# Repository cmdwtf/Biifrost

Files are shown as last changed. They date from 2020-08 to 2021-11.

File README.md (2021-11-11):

# Biifröst Bridge
A PCB bridge from Odiin to Screen

### Board Images
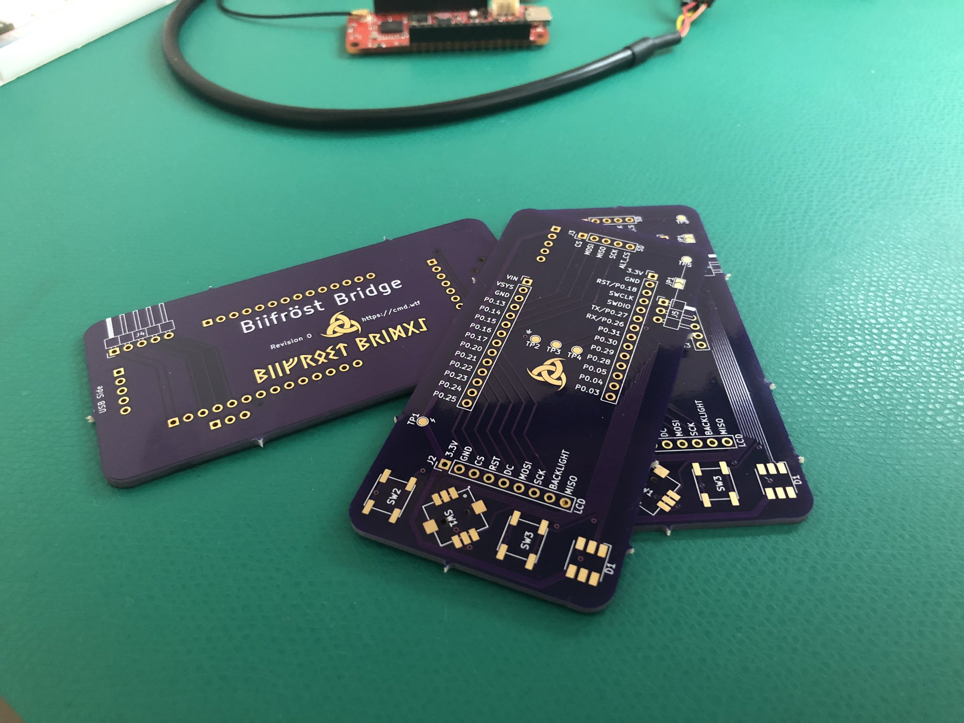
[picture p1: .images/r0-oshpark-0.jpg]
Revision 0 Fab 0
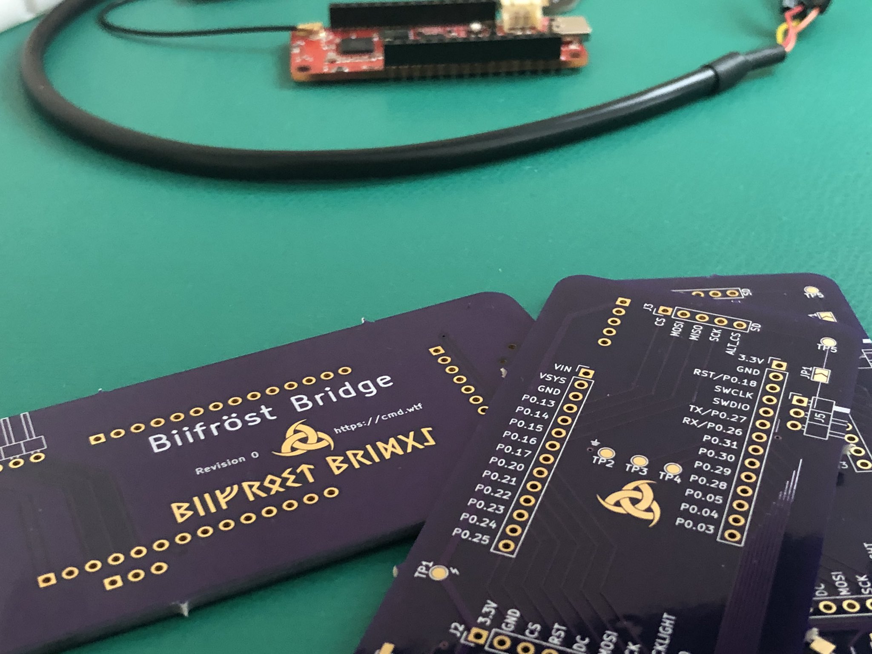
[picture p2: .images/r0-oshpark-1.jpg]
Revision 0 Fab 1
 
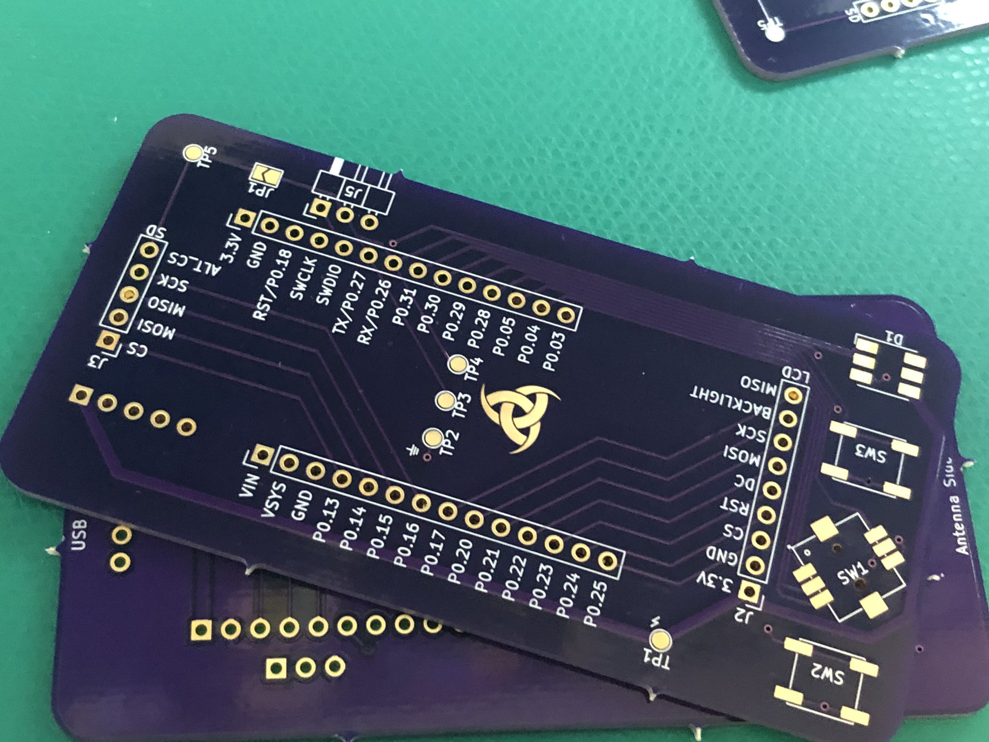
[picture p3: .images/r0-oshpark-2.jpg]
Revision 0 Fab 2
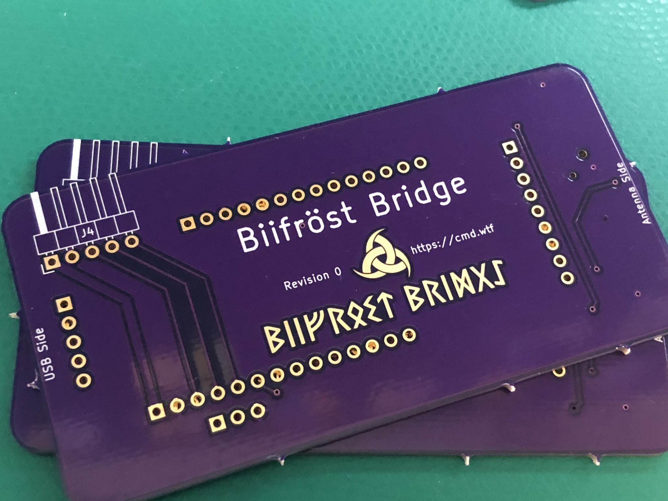
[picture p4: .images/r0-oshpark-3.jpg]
Revision 0 Fab 3
 
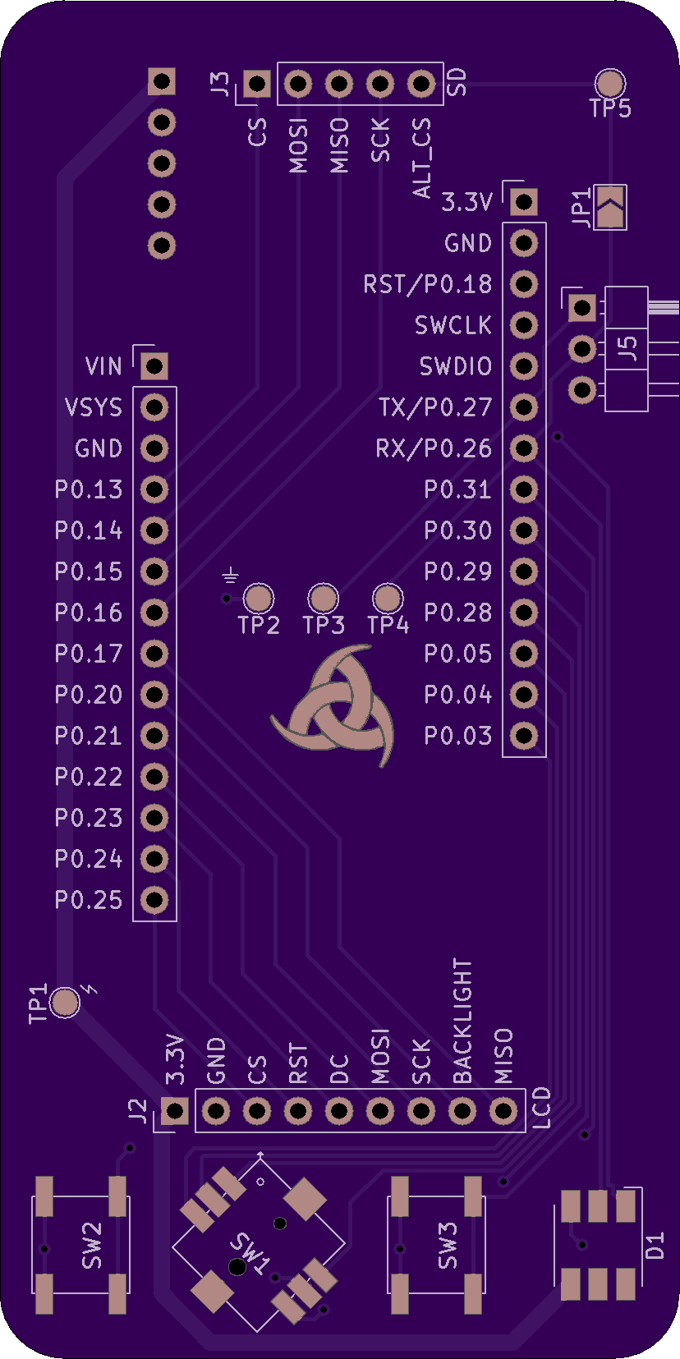
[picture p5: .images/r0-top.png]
Revision 0 Top
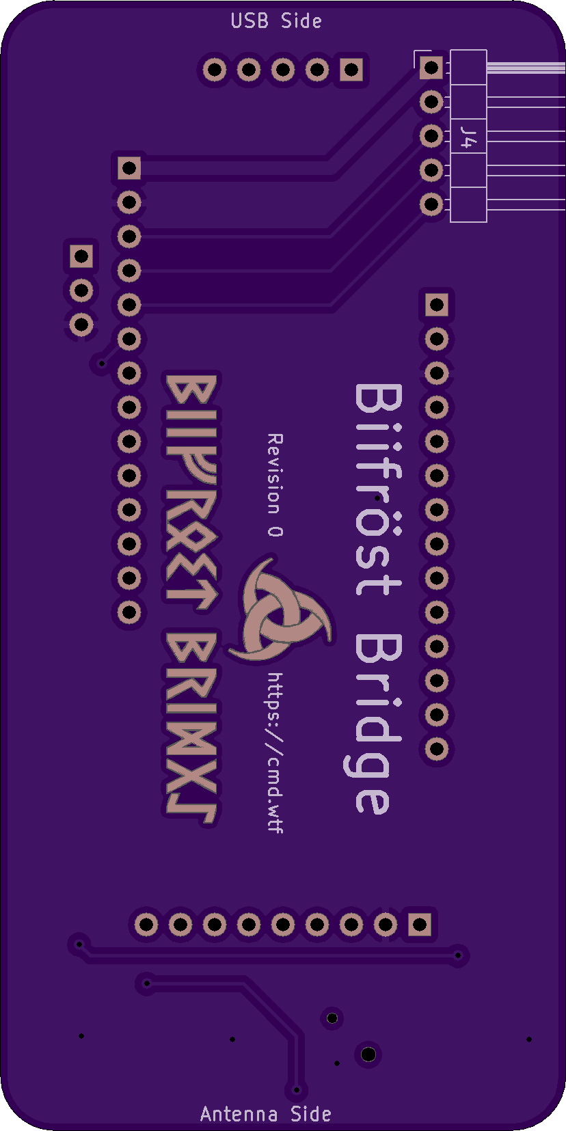
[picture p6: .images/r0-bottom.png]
Revision 0 Bottom
 

# EDA
Biifröst Bridge was designed and created with [KiCad EDA](https://kicad.org/) 5.1.6.

# License
This repository is licensed under Apache-2.0 WITH SHL-2.1. Please see LICENSE.md for more information.

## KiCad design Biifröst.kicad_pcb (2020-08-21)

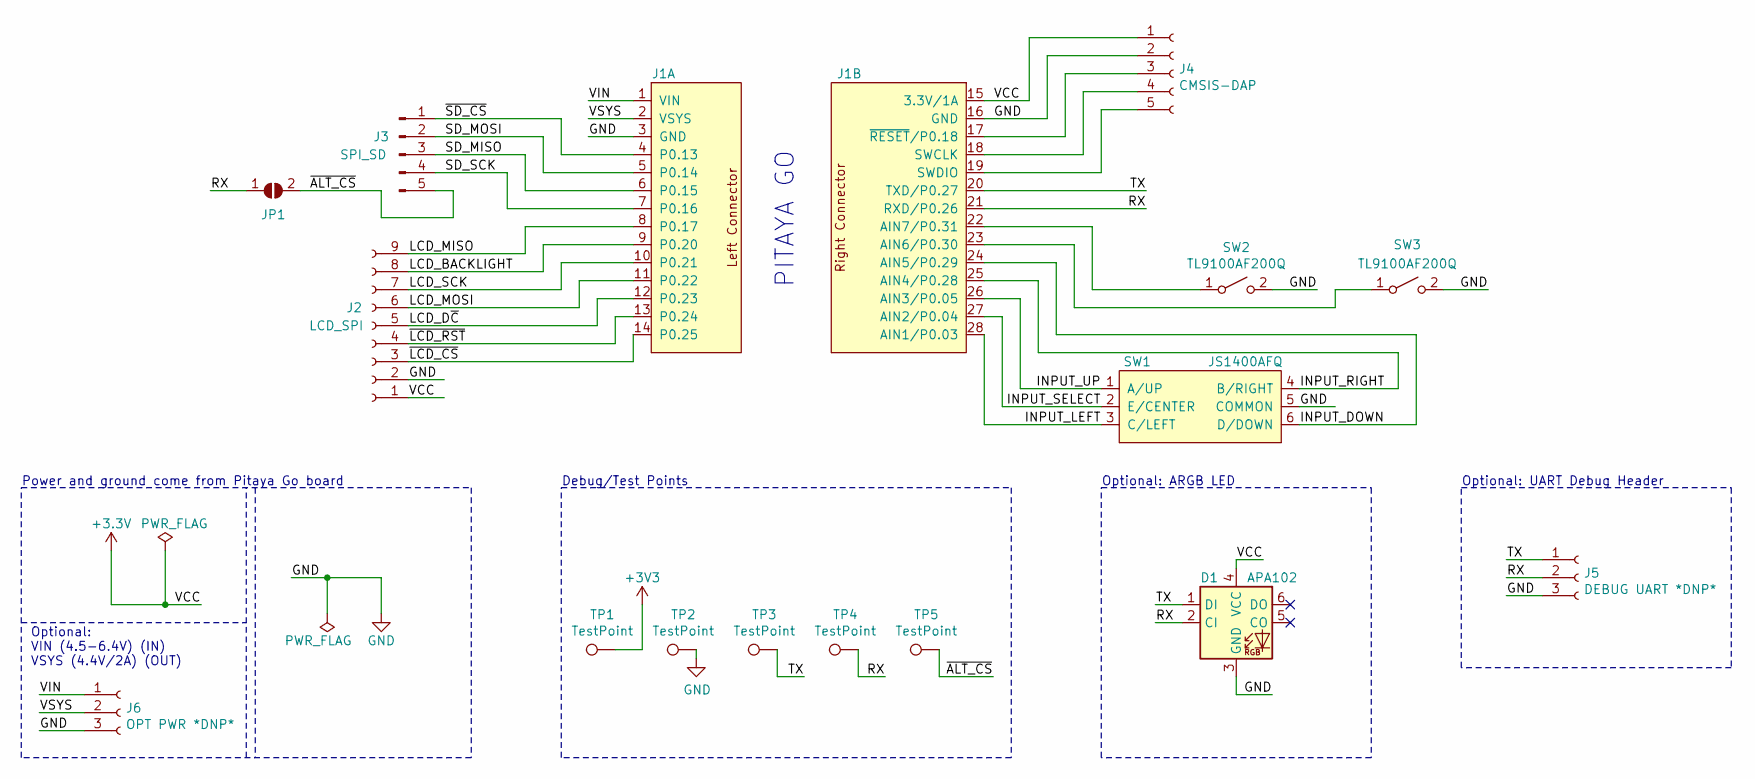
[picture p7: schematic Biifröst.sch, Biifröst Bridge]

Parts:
D1: APA102; LED_RGB_5050-6
J1: Pitaya_Go; Pitaya_Go_Headers
J2: LCD_SPI; PinHeader_1x09_P2.54mm_Vertical
J3: SPI_SD; PinHeader_1x05_P2.54mm_Vertical
J4: CMSIS-DAP; PinHeader_1x05_P2.54mm_Horizontal
J5: DEBUG UART *DNP*; PinHeader_1x03_P2.54mm_Horizontal
J6: OPT PWR *DNP*; PinHeader_1x03_P2.54mm_Horizontal
JP1: SolderJumper_2_Open; SolderJumper-2_P1.3mm_Open_TrianglePad1.0x1.5mm
SW1: JS1400AFQ; JS1400
SW2, SW3: TL9100AF200Q; TL9100
TP1, TP2, TP3, TP4, TP5: TestPoint; TestPoint_Pad_D1.5mm

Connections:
/INPUT_DOWN: J1.24 (AIN5/P0.29), SW1.6 (D/DOWN)
/INPUT_LEFT: J1.28 (AIN1/P0.03), SW1.3 (C/LEFT)
/INPUT_RIGHT: J1.25 (AIN4/P0.28), SW1.4 (B/RIGHT)
/INPUT_SELECT: J1.27 (AIN2/P0.04), SW1.2 (E/CENTER)
/INPUT_UP: J1.26 (AIN3/P0.05), SW1.1 (A/UP)
/LCD_BACKLIGHT: J1.9 (P0.20), J2.8
/LCD_D~C~: J1.12 (P0.23), J2.5
/LCD_MISO: J1.8 (P0.17), J2.9
/LCD_MOSI: J1.11 (P0.22), J2.6
/LCD_SCK: J1.10 (P0.21), J2.7
/RX: D1.2 (CI), J1.21 (RXD/P0.26), J5.2, JP1.1 (A), TP4.1
/SD_MISO: J1.6 (P0.15), J3.3
/SD_MOSI: J1.5 (P0.14), J3.2
/SD_SCK: J1.7 (P0.16), J3.4
/TX: D1.1 (DI), J1.20 (TXD/P0.27), J5.1, TP3.1
/VIN: J1.1 (VIN), J6.1
/VSYS: J1.2 (VSYS), J6.2
/~ALT_CS~: J3.5, JP1.2 (B), TP5.1
/~LCD_CS~: J1.14 (P0.25), J2.3
/~LCD_RST~: J1.13 (P0.24), J2.4
/~SD_CS~: J1.4 (P0.13), J3.1
GND: D1.3 (GND), J1.3 (GND), J1.16 (GND), J2.2, J4.2, J5.3, J6.3, SW1.5 (COMMON), SW2.2 (B), SW3.2 (B), TP2.1
unnamed: J1.17 (~RESET~/P0.18), J4.3
unnamed: J1.18 (SWCLK), J4.4
unnamed: J1.19 (SWDIO), J4.5
unnamed: J1.22 (AIN7/P0.31), SW2.1 (A)
unnamed: J1.23 (AIN6/P0.30), SW3.1 (A)

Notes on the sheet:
PITAYA GO
Power and ground come from Pitaya Go board
Optional: ARGB LED
Optional: UART Debug Header
Debug/Test Points
Optional: VIN (4.5-6.4V) (IN) VSYS (4.4V/2A) (OUT)

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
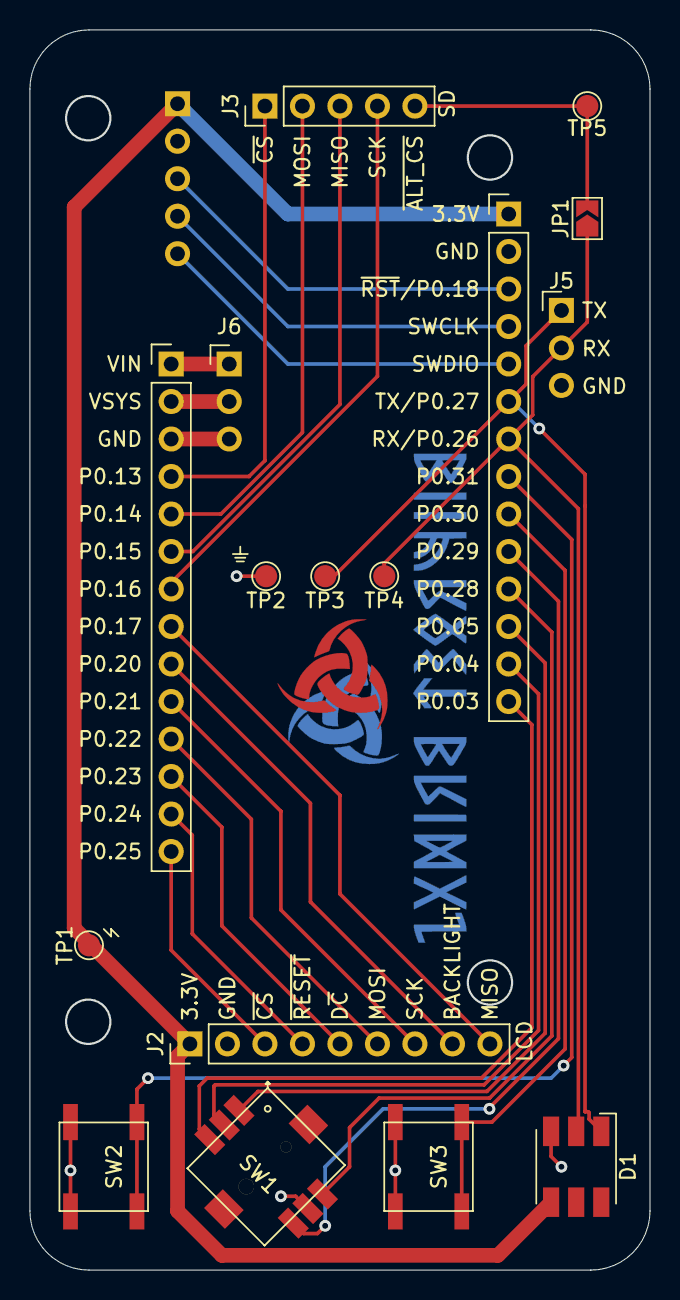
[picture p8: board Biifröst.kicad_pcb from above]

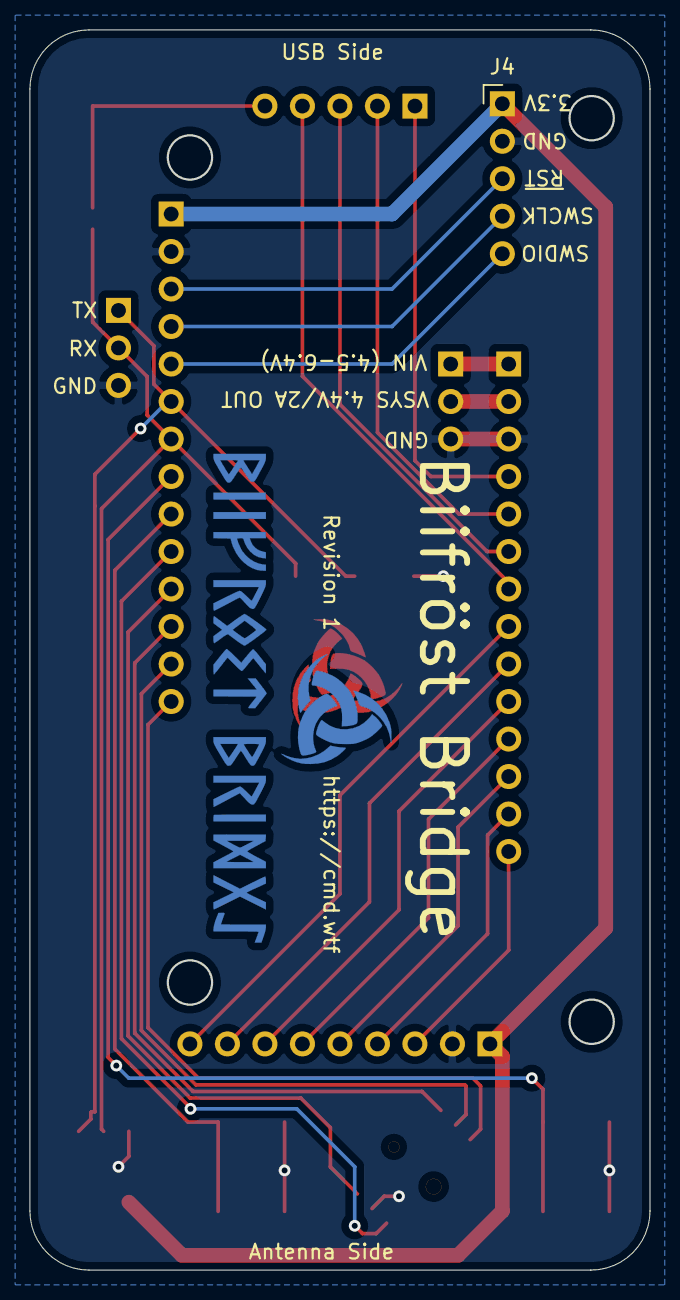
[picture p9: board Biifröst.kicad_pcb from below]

Board: 2 copper layers, 42.0 x 84.0 mm, 19 parts (3 on the bottom side), 28 nets.

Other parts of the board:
Ref**: Val**; Horn_of_Odin
Ref**#2: Val**; Logo
Ref**#3: Val**; Wordmark

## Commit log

2020-08-03 WIP r0.
    [Biifröst.kicad_pcb, Biifröst.sch]
2020-08-03 Add Wordmark/Icon for flair.
    [Biifröst.kicad_pcb]
2020-08-11 Add board images for r0.
2020-08-18 Add several models.
    Including Pitaya Go, both E-Switch types.
    Added some board dimensions too.
    [Biifröst.kicad_pcb]
2020-08-18 Update pins to have not bars where they should be.
    And fixed a dumb typo on a net name.
    [Biifröst.kicad_pcb, Biifröst.sch]
2020-08-19 Add actual board images, fab'd by oshpark.
2020-08-19 Add/adjust some silks. Bump to r1.
    Still need to test the apa102 at 3.3v before I send it up for another spin.
    [Biifröst.kicad_pcb, Biifröst.sch]
2020-08-21 Add VIN/VSYS breakout. Add 4 hole cuts that will line up with sister boards.
    2 hole cuts will align with the pitaya go holes (1 top, 1 bottom, on one side)
    2 hole cuts will align with the LCD board holes (1 top, 1 bottom, opposite side from pitaya.)
    Not perfectly ideal, but required no trace moves, and they may be useful.
    [Biifröst.kicad_pcb, Biifröst.sch]
2020-08-21 Add measurements to new hole cuts.
    [Biifröst.kicad_pcb]
2021-11-10 Update README.md
    https://forum.kicad.info/t/warning-avoid-all-links-to-kicad-pcb-org-use-kicad-org/31521
